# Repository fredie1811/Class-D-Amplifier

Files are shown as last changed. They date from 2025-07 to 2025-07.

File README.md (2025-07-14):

# Class D Audio Amplifier

This project involves the design and implementation of a 2-layer PCB for a *Class D audio amplifier* using a *half-bridge topology* and integrated *Bluetooth streaming* via the *MHM-28 module*. The amplifier is capable of driving a speaker with high efficiency using Pulse Width Modulation (PWM), with clean audio recovery using an LC filter.

## 🔧 Features

* Class D half-bridge topology for efficient audio amplification
* Bluetooth audio streaming using MHM-28 module
* PWM generation with TLC555 timer
* Signal conditioning and dead-time control using LM393 and 74HC04
* Gate driving with IRS2113 for high-side and low-side MOSFET control
* LC filter output for analog audio reconstruction
* 2-layer PCB designed in KiCad

## 📐 System Architecture

| Module | Description |
| --- | --- |
| TLC555 Timer | Triangle waveform generator for PWM modulation |
| LM393 Comparator | Converts audio to PWM by comparing input with reference |
| IRS2113 | High/low-side MOSFET driver for half-bridge control |
| IRLZ44N MOSFETs  | Power stage switches |
| LC Filter | Reconstructs analog signal from PWM output |
| MHM-28 Module | Bluetooth V4.0 A2DP module for wireless audio |
| LM7805 / LM7812  | Linear regulators for 5V and 12V power rails |

## 📊 Technical Specifications

| Parameter | Value |
| --- | --- |
| Supply Voltage | 12V |
| PWM Frequency | \~200 kHz |
| LC Filter Cutoff  | \~38.6 kHz |
| Output Power | \~10–20 W |
| Efficiency | >90% |
| PCB Size | 2-layer board |
| Bluetooth Support | Yes (MHM-28, stereo input) |

## 🔋 Power Supply

* LM7805: 5V logic rail
* LM7812: 12V gate driver rail
* Capacitive decoupling at regulator input/output

## 📡 Bluetooth Audio Interface

The MHM-28 module supports:

* Bluetooth V4.0 with A2DP
* Stereo analog output
* Easy pin-header integration
* Direct input to comparator stage

## 🎯 Applications

* Portable wireless audio systems
* DIY speaker projects
* Embedded systems with audio output
* Energy-efficient signal amplification

## 🧠 Learnings

* Class D amplifier design theory
* PWM signal processing and dead-time logic
* High-frequency PCB layout techniques
* Filter design and frequency response analysis
* Bluetooth module integration

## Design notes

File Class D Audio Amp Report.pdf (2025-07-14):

# Internship Project Report

# Title: 2-Layer PCB Design for Half-Bridge Class D Bluetooth Audio Amplifier

### 1. Project Overview

This project focused on the schematic design and PCB layout of a Class D audio amplifier using a half-bridge topology on a 2-layer PCB. The amplifier is capable of driving a speaker with high efficiency, using Pulse Width Modulation (PWM) techniques to amplify the audio signal. A key feature of the system is the integration of the MHM-28 Bluetooth module, which enables wireless audio streaming. The project involved extensive work in analog and digital electronics, filter design, power electronics, and PCB layout using KiCad.

### 2. Why Class D Amplifier?

The amplifier design employs a Class D topology, which is known for:

- High Efficiency: Typically >90%, due to transistors operating as switches rather than linear amplifiers
- Compact Size: No need for large heatsinks or power-hungry biasing components
- Low Heat Dissipation: Minimal energy lost as heat, important for embedded and portable systems
- Suitability for Wireless Audio Systems: Efficiency and size are critical in battery-operated or space-constrained environments

In contrast to Class A, B, or AB amplifiers, Class D operates transistors in either full-on or full-off states, drastically reducing power loss and improving overall efficiency.

### 3. Why Half-Bridge Topology?

The choice of half-bridge topology was motivated by several key advantages:

- Fewer Components: Only two switching transistors required, reducing cost and complexity
- Simpler Gate Drive: Easily implemented with a dedicated driver like the IRS2113
- Compact Design: Ideal for 2-layer PCBs with limited space
- Single-Supply Operation: Suitable for unipolar speaker connections

While full-bridge topologies provide differential output and potentially higher power, they also require more components and increased design complexity. For this application, the half-bridge met all performance and efficiency requirements.

### 4. System Block Diagram Overview

Block | Function
Power Supply | Provides 5V and 12V rails via linear regulators
TLC555 Timer | Generates a triangle waveform for PWM modulation
LM393 Comparator | Compares audio input with reference waveform to create PWM
74HC04 Inverters | Insert dead time and shape signals
IR2113 Driver | Drives high-side and low-side MOSFETs
IRLZ44N MOSFETs | Perform power switching to drive speaker load
LC Filter | Reconstructs audio from PWM output
MHM-28 Module | Receives Bluetooth audio input

### 5. Bluetooth Interfacing with MHM-28 Module

The MHM-28 Bluetooth module enables seamless audio streaming from devices such as smartphones or laptops. Key features include:

- Bluetooth V4.0 with A2DP profile
- Stereo analog audio output
- Compact and low-power design
- Simple integration via header pins

In this project, the stereo output is connected to the inverting input of the comparator (LM393), where it is modulated against a reference triangle waveform to create a PWM representation of the input audio signal.

### 6. Power Supply Design

Two linear regulators were used:

- LM7805 (U5): Provides a regulated 5V supply for logic-level devices and control circuitry
- LM7812 (U6): Supplies a stable 12V rail required for the IRS2113 gate driver and MOSFET switching

The regulators are stabilized with decoupling capacitors:

- Input: 47µF electrolytic
- Output: 47µF electrolytic + 220nF ceramic (for high-frequency stability)

### 7. PWM Generation and Signal Conditioning

The TLC555 timer is configured in astable mode to generate a triangle or sawtooth waveform. This waveform is fed to one input of the LM393 comparator. The other input receives the analog audio signal (from MHM-28), resulting in a PWM signal whose duty cycle varies according to the audio amplitude.

To ensure proper switching and protect the MOSFETs, dead time is introduced using 74HC04 inverters to delay signal edges and prevent shoot-through currents.

### 8. Driver and Switching Stage

The IRS2113 high- and low-side driver IC is responsible for:

- Driving the gates of the IRFZ44N MOSFETs
- Level-shifting logic signals to 12V gate control
- Ensuring proper timing and dead-time insertion between high-side and low-side switching

The IRFZ44Ns were chosen for their:

- Fast switching times
- High current capacity
- Low Rds(on) for efficient conduction

### 9. LC Output Filter Design and Calculations

To convert the PWM back into an analog signal, an LC low-pass filter is employed.

Filter Type: Parallel LC configuration

This configuration resonates at the desired cutoff frequency, shunting high-frequency switching components to ground.

Target Cutoff Frequency:

The desired cutoff frequency was chosen to be: (f_c , , )

This ensures:

- Audio frequencies (<20 kHz) are passed
- Switching frequencies (~200 kHz) are effectively attenuated Component Values:
- L = 16.5 µH
- C = 1.03 µF

Formula:

(f0 = 1/2π(√LC))

Substituting the values: (f0 = 38.6KHz)

This confirms that the parallel LC filter is correctly tuned to the switching frequency region, offering excellent attenuation of unwanted harmonics.

### 10. PCB Layout and Implementation

The circuit was implemented on a 2-layer PCB, with careful consideration for:

- Grounding and decoupling: Ground planes and bypass capacitors placed close to ICs
- Minimized loop area: Power and signal paths routed efficiently to reduce EMI
- MOSFET layout: Placed near driver for minimal gate trace delay
- Bluetooth module: Socketed for ease of debugging and modularity

The design was completed using KiCad

### 11. Results and Observations

Parameter | Value
Efficiency | >90%
Max Output Power | ~10–20W depending on load and supply
Cutoff Frequency | 38.6 kHz
PCB Layers | 2
Bluetooth Streaming | Supported via MHM-28

### 12. Conclusion

From the project the following key outputs can be obtained:

- Understanding of Class D amplifier theory and implementation
- Practical experience with analog comparator circuits and PWM control
- Hands-on design and routing of a 2-layer PCB for mixed-signal systems
- Integration of wireless streaming modules (MHM-28)
- Development of skills in power electronics, filter design, and circuit layout

The amplifier successfully achieved clean, efficient audio amplification with wireless control, suitable for both portable and fixed audio applications.

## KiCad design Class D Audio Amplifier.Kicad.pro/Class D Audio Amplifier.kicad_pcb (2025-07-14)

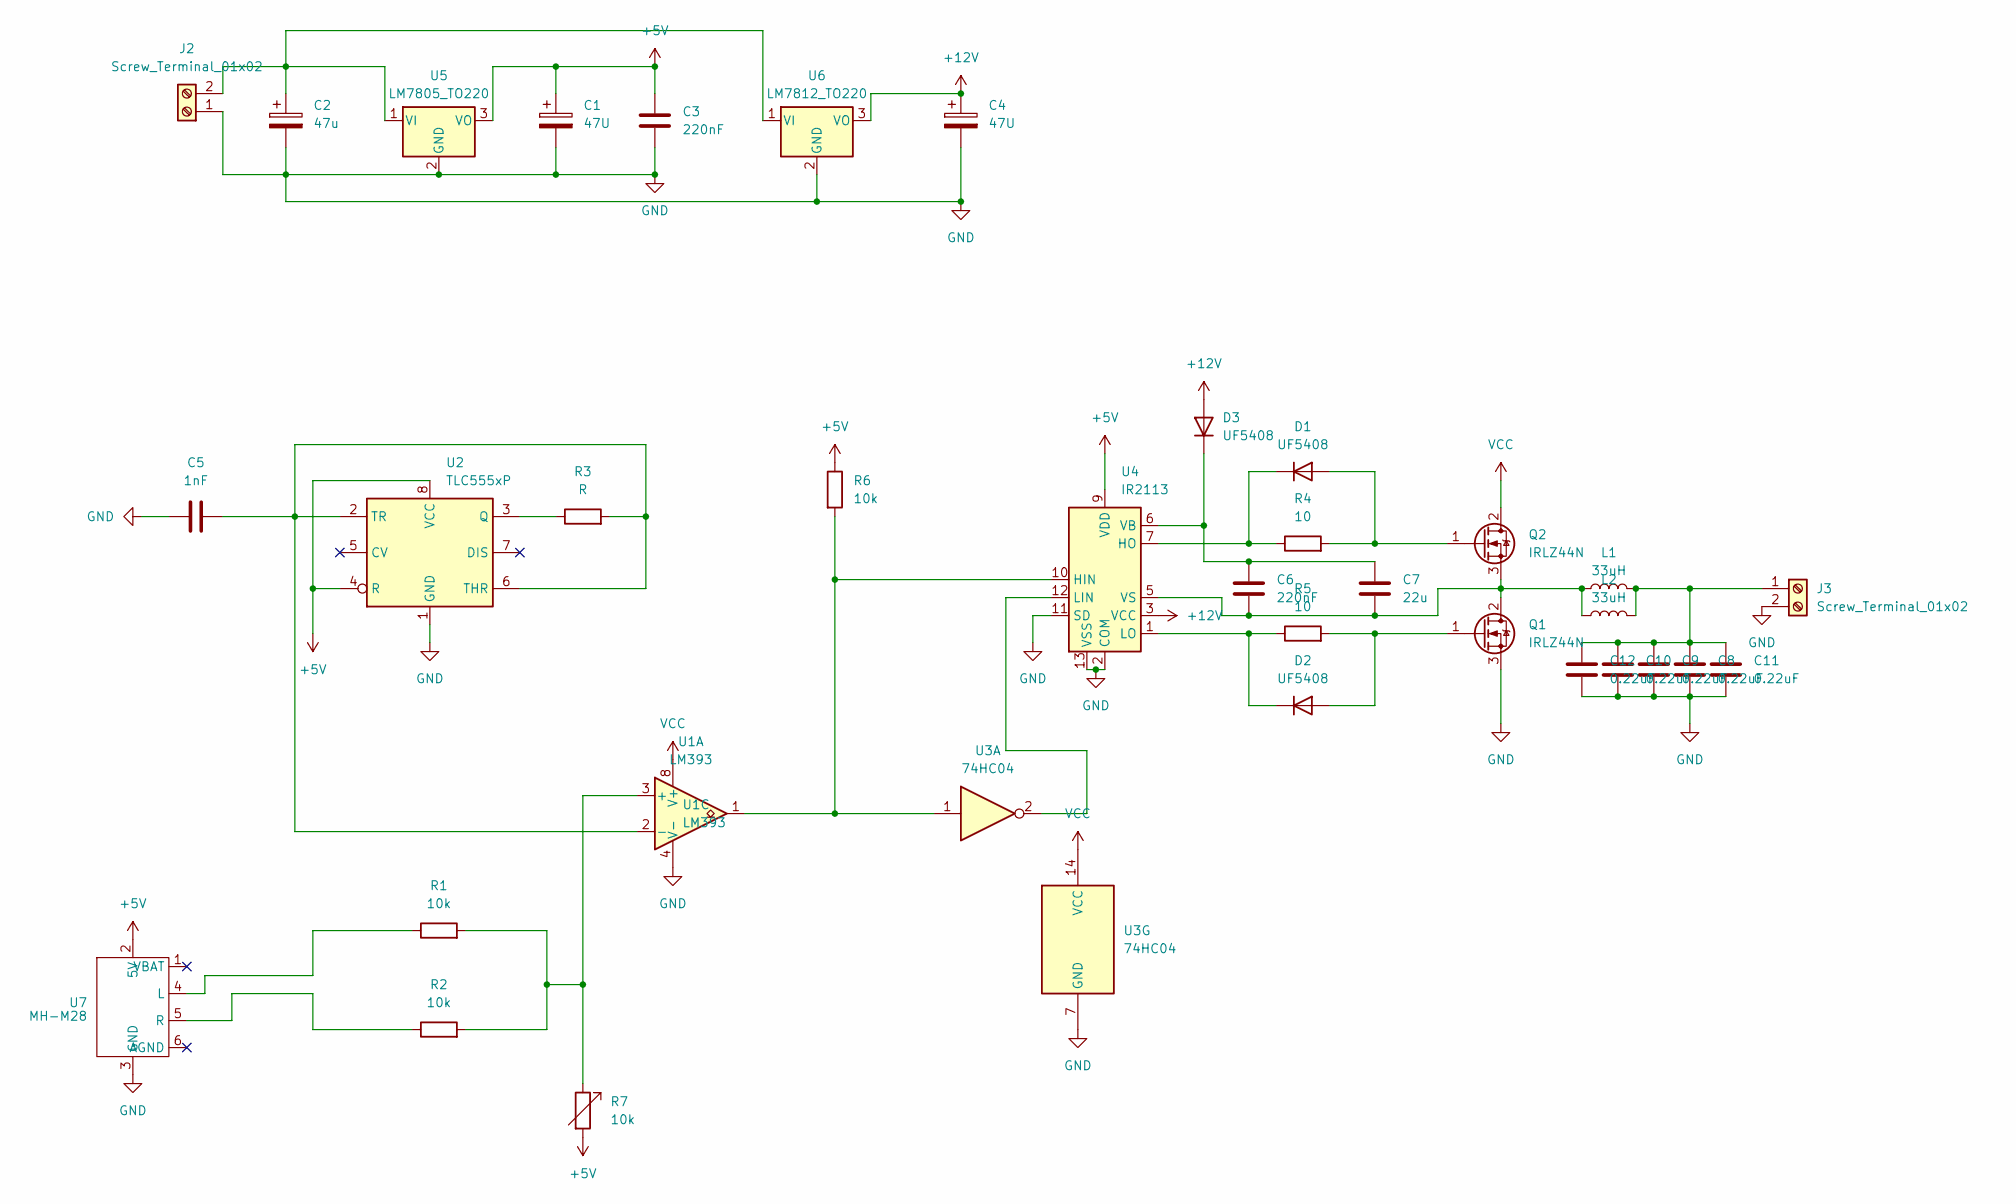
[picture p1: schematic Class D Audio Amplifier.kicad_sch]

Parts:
C1, C4: 47U; C_Radial_D5.0mm_H11.0mm_P2.00mm
C2: 47u; C_Radial_D5.0mm_H11.0mm_P2.00mm
C3, C6: 220nF; C_Disc_D4.3mm_W1.9mm_P5.00mm
C5: 1nF; C_Disc_D4.3mm_W1.9mm_P5.00mm
C7: 22u; C_Radial_D5.0mm_H11.0mm_P2.00mm
C8, C9, C10, C11, C12: 0.22uF; C_Rect_L26.5mm_W10.5mm_P22.50mm_MKS4
D1, D2, D3: UF5408; D_DO-201AD_P15.24mm_Horizontal
J2, J3: Screw_Terminal_01x02; TerminalBlock_Phoenix_MKDS-1,5-2-5.08_1x02_P5.08mm_Horizont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
L1, L2: 33uH; L_Radial_D8.7mm_P5.00mm_Fastron_07HCP
Q1, Q2: IRLZ44N; TO-220-3_Vertical
R1, R2, R6, R7: 10k; R_Axial_DIN0204_L3.6mm_D1.6mm_P7.62mm_Horizontal
R3: R; R_Axial_DIN0204_L3.6mm_D1.6mm_P7.62mm_Horizontal
R4, R5: 10; R_Axial_DIN0204_L3.6mm_D1.6mm_P7.62mm_Horizontal
U1: LM393; DIP794W45P254L959H508Q8
U2: TLC555xP; DIP-8_W7.62mm
U3: 74HC04
U4: IR2113; DIP-14_W7.62mm
U5: LM7805_TO220; TO-220-3_Vertical
U6: LM7812_TO220; TO-220-3_Vertical
U7: MH-M28

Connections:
+5V: C1.1, C3.1, R6.1, R7.2, U2.4 (R), U2.8 (VCC), U4.9 (VDD), U5.3 (VO), U7.2 (5V)
+12V: C4.1, D3.2 (A), U4.3 (VCC), U6.3 (VO)
GND: C1.2, C2.2, C3.2, C4.2, C5.1, C8.2, C9.2, C10.2, C11.2, C12.2, J2.1, J3.2, Q1.3 (S), U1.4 (V-), U2.1 (GND), U3.7 (GND), U4.2 (COM), U4.11 (SD), U4.13 (VSS), U5.2 (GND), U6.2 (GND), U7.3 (GND)
unnamed: D1.2 (A), Q2.1 (G), R4.2
unnamed: D1.1 (K), R4.1, U4.7 (HO)
unnamed: D2.2 (A), Q1.1 (G), R5.2
unnamed: D2.1 (K), R5.1, U4.1 (LO)
unnamed: C6.1, C7.1, D3.1 (K), U4.6 (VB)
unnamed: C2.1, J2.2, U5.1 (VI), U6.1 (VI)
unnamed: C8.1, C9.1, C10.1, C11.1, C12.1, J3.1, L1.2, L2.2
unnamed: C6.2, C7.2, L1.1, L2.1, Q1.2 (D), Q2.3 (S), U4.5 (VS)
unnamed: R1.2, R2.2, R7.1, U1.3 (+)
unnamed: C5.2, R3.2, U1.2 (-), U2.2 (TR), U2.6 (THR)
unnamed: R3.1, U2.3 (Q)
unnamed: R6.2, U1.1, U3.1, U4.10 (HIN)
unnamed: U3.2, U4.12 (LIN)
unnamed: R1.1, U7.4 (L)
unnamed: R2.1, U7.5 (R)
VCC: Q2.2 (D), U1.8 (V+), U3.14 (VCC)

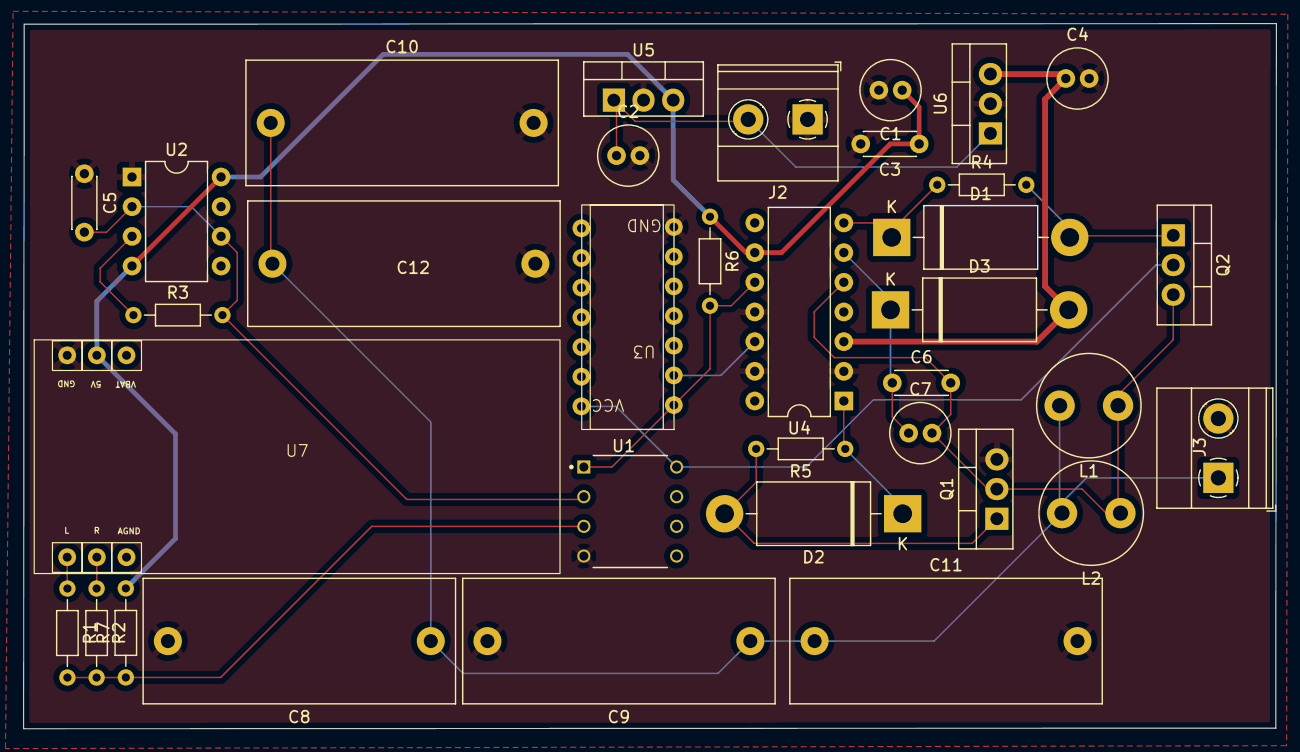
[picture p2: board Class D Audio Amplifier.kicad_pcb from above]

Board: 2 copper layers, 107.2 x 60.3 mm, 35 parts (0 on the bottom side), 19 nets.
